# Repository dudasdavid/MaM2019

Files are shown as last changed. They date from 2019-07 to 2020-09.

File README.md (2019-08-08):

# MaM2019

Drivetrain:
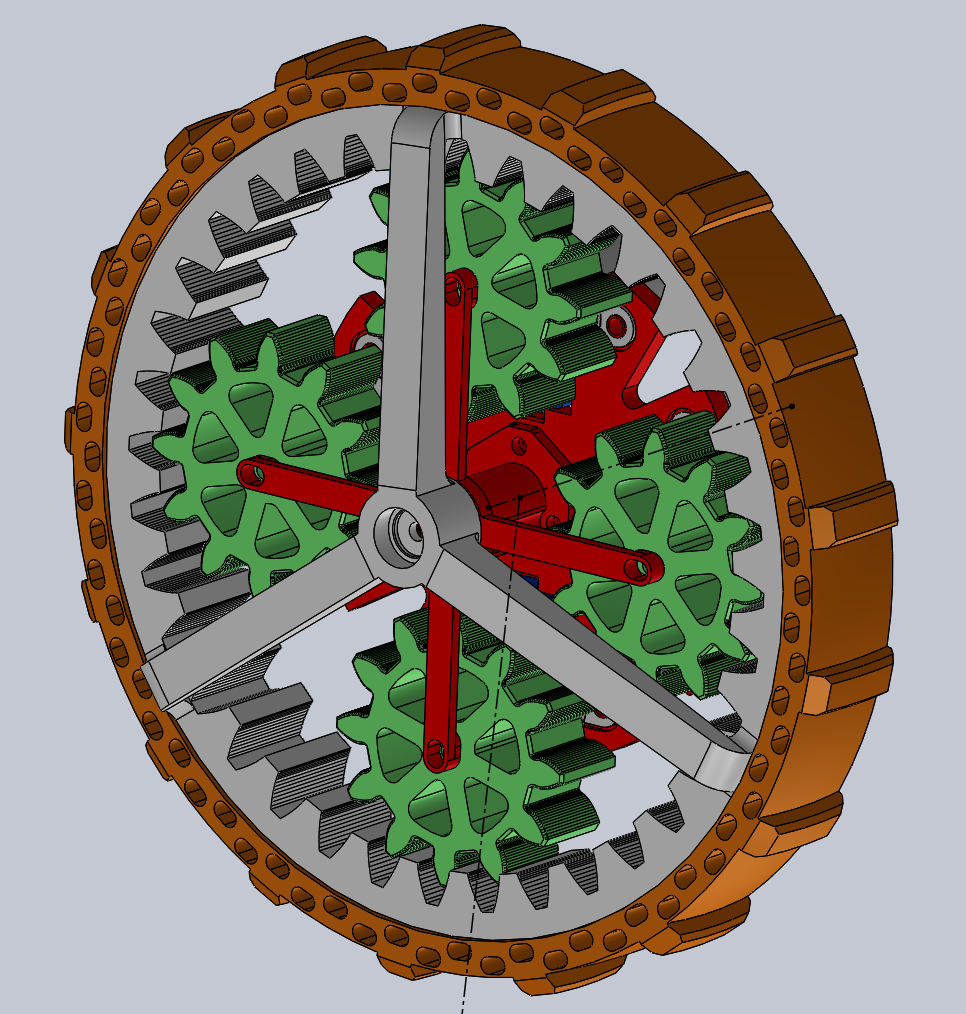
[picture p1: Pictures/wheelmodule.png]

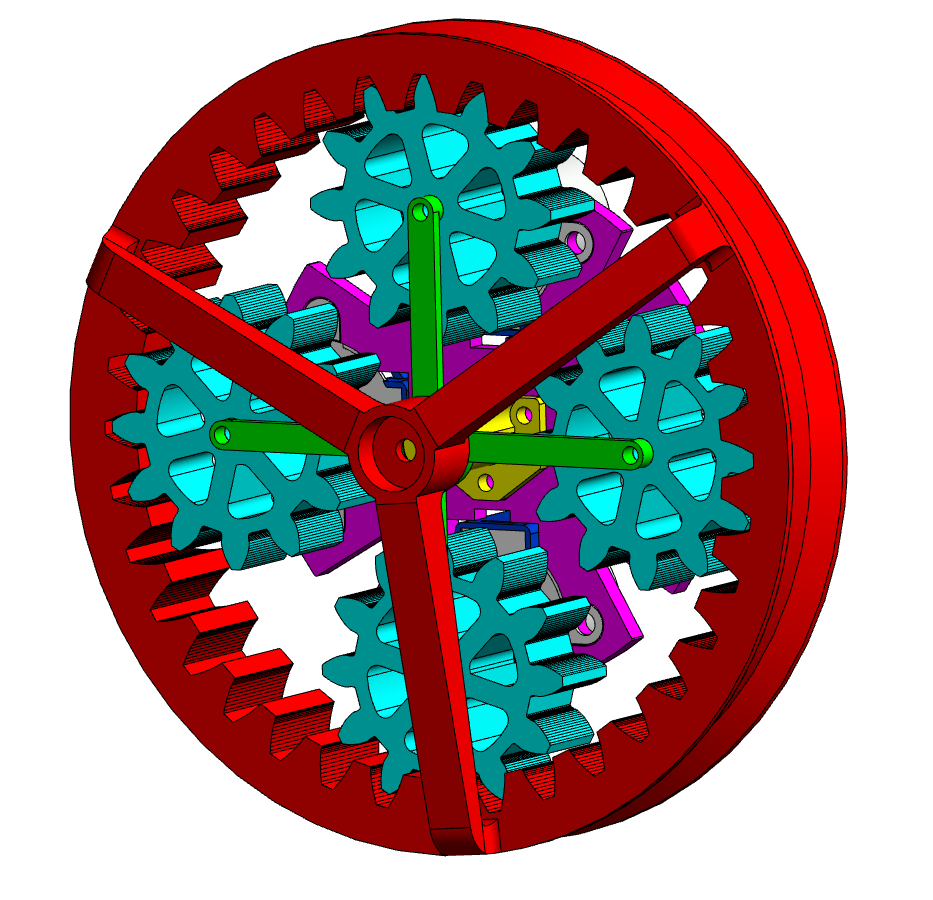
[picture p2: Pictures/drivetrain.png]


Mechanical parts:
- 4x M3x10: Spur gears --> Spur ribs
- 1x M3x25: Ring gear --> main axis
- 8x M3x8: Motors --> baseplate
- 3x M3x???: Main axis --> baseplate --> L bracket
- 4x M3x???: L bracket --> Chassis
- 2x 623 2Z Bearing (3X10X4): Ring gear

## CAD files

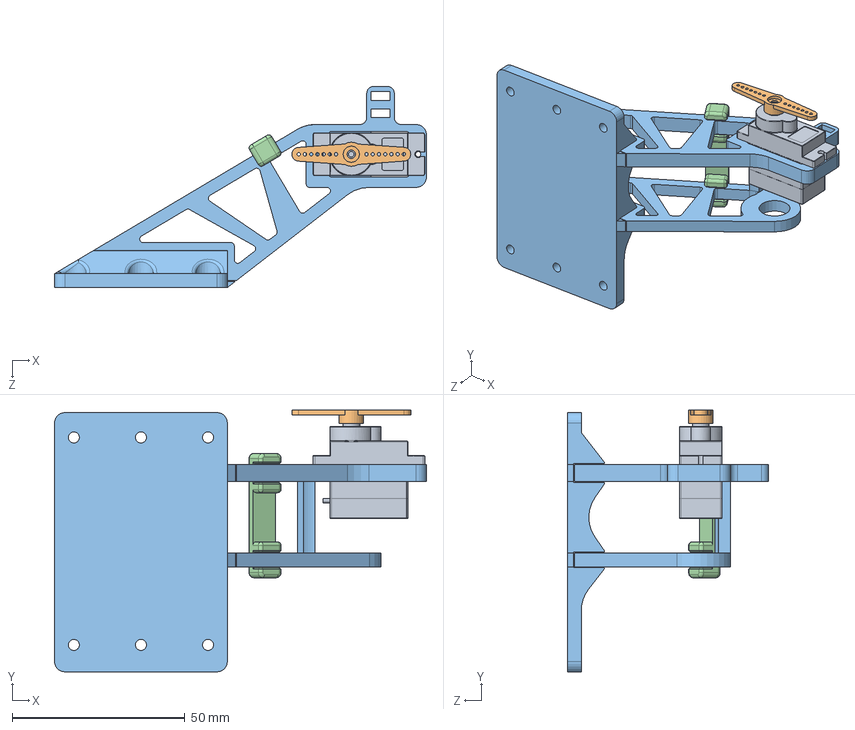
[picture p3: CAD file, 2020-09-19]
Mechanics/Solidworks/_LIFT.SLDASM
107.6 x 75.7 x 58.1 mm
microservoSG90
Part9^_LIFT
rib^_LIFT

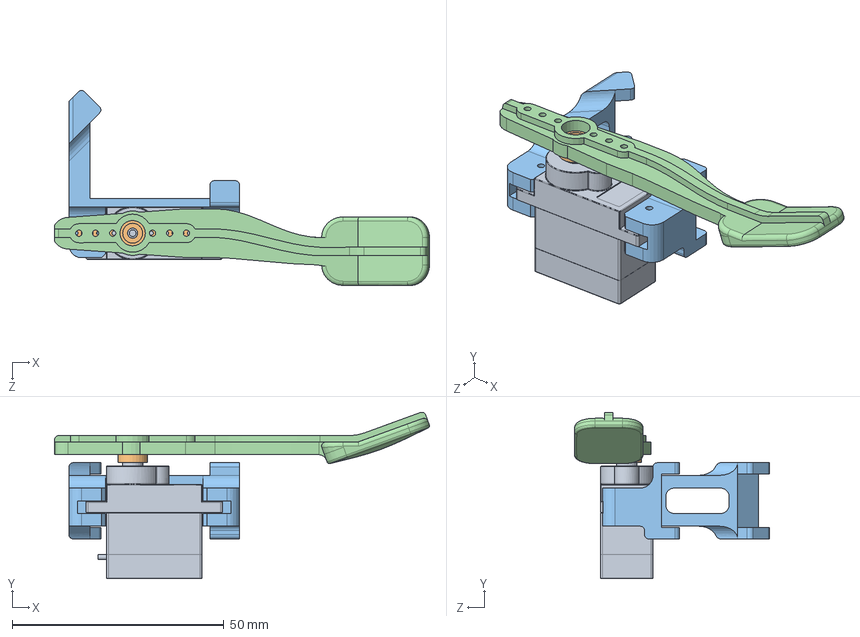
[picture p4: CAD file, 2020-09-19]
Mechanics/Solidworks/opener.SLDASM
88.6 x 39.3 x 46.1 mm
microservoSG90
microservoArm
Part5^opener
Part6^opener

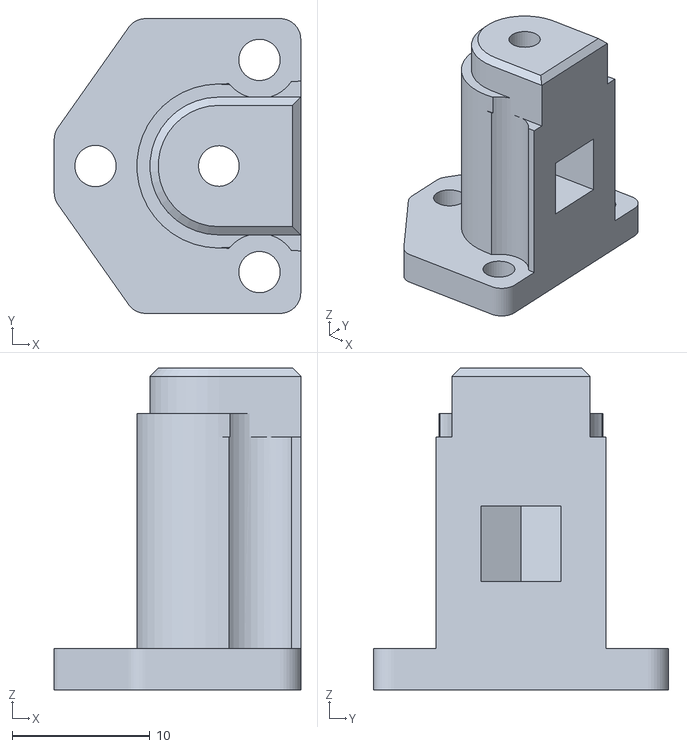
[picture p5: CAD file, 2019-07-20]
Mechanics/STL/MainAxis.STL
17.9 x 21.4 x 23.4

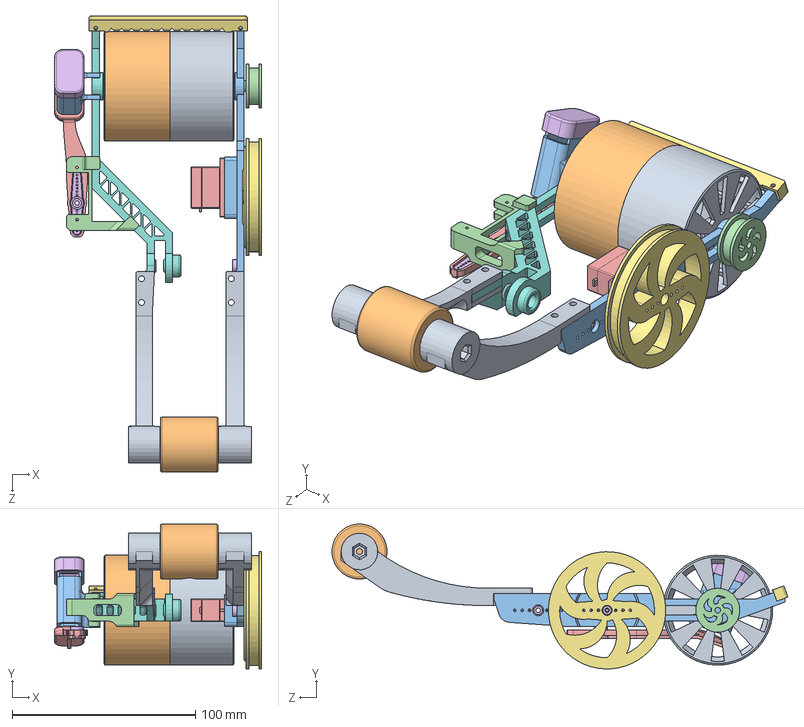
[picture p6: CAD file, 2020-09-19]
Mechanics/Solidworks/_COLLECTOR.SLDASM
113.1 x 79.1 x 248.8 mm
Copy of cylinder_1^_COLLECTOR
cylinder_2^_COLLECTOR
Part6^_COLLECTOR
Part7^_COLLECTOR
microservoArm x 3
Part8^_COLLECTOR
Part11^_COLLECTOR
bag
Part5^opener
Part6^opener
Part3^_COLLECTOR
Part9^_COLLECTOR

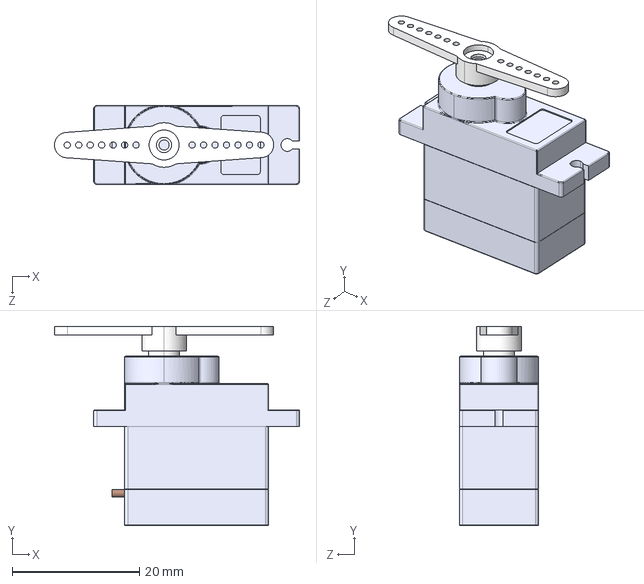
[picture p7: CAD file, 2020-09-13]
Mechanics/Solidworks/SG90/microservoAssembly.STEP
38.4 x 31.3 x 12.4 mm
microservoSG90
microservoArm_A2

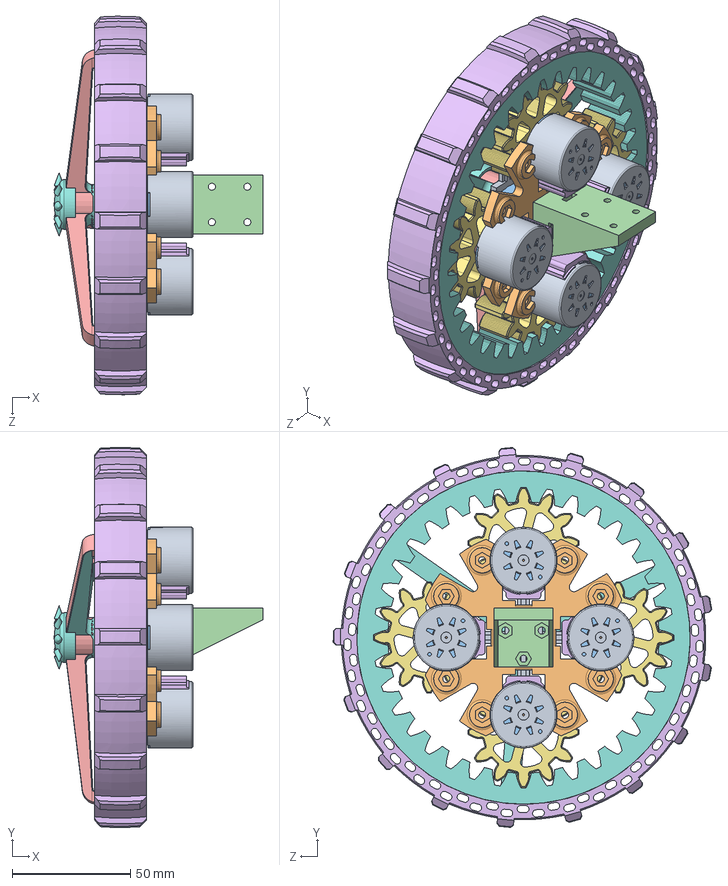
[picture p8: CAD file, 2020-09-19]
Mechanics/Solidworks/_DRIVE_v1.SLDASM
88.2 x 160.7 x 160.1 mm
El1 - 28BYJ-48 - 5 VDC x 4
El2 - 28BYJ-48 - 5 VDC x 4
El6 - 28BYJ-48 - 5 VDC x 4
El4 - 28BYJ-48 - 5 VDC x 4
El5 - 28BYJ-48 - 5 VDC x 4
El7 - 28BYJ-48 - 5 VDC x 4
El3 - 28BYJ-48 - 5 VDC x 4
El8 - 28BYJ-48 - 5 VDC x 4
El9 - 28BYJ-48 - 5 VDC x 4
El10 - 28BYJ-48 - 5 VDC x 4
El11 - 28BYJ-48 - 5 VDC x 4
El12 - 28BYJ-48 - 5 VDC x 4
El13 - 28BYJ-48 - 5 VDC x 4
El14 - 28BYJ-48 - 5 VDC x 4
SpurGear x 4
BasePlate
MainAxis^_DRIVE_v1
Lbracket
RingGear_corrected_diameter
RubberTire
SpurRibs_corrected
Cap^_DRIVE_v1

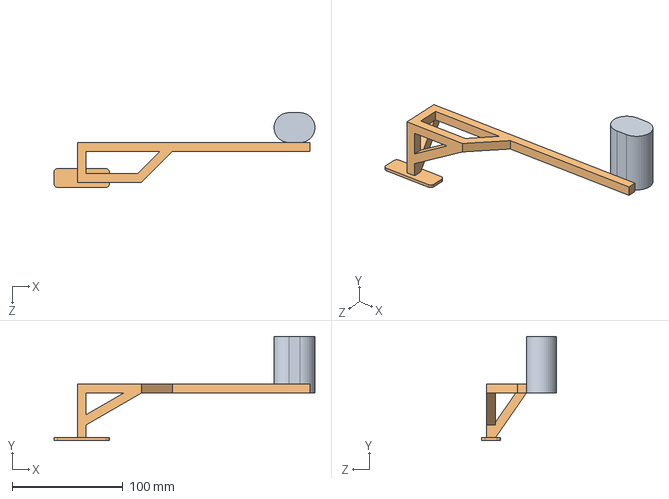
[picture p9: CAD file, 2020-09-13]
Mechanics/Solidworks/_EJECTOR.SLDASM
235.7 x 93.9 x 67.5 mm
Part2^_EJECTOR
Part7^_EJECTOR

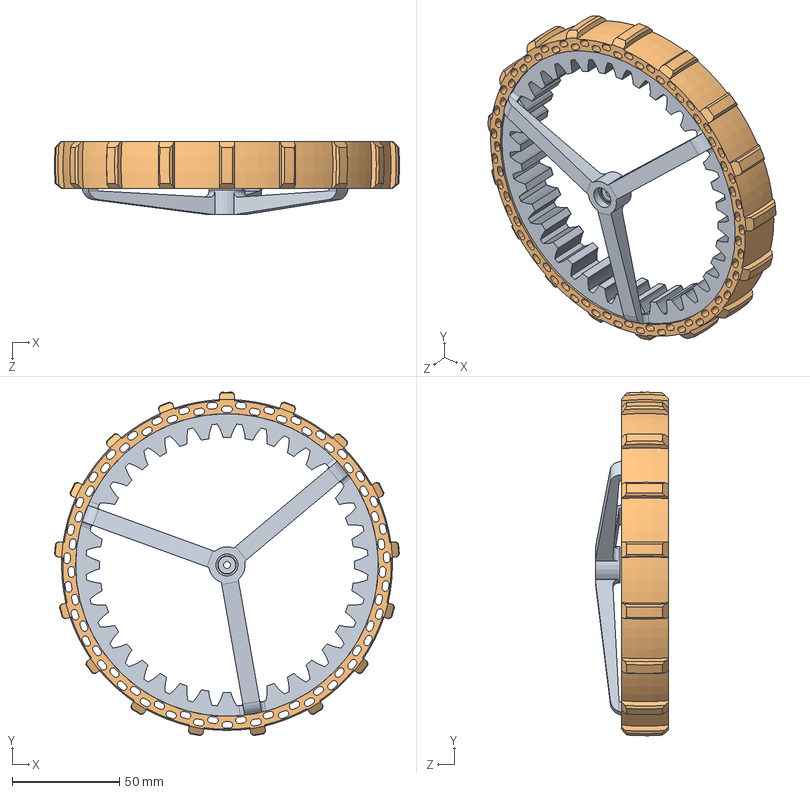
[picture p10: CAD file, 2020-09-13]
Mechanics/Solidworks/_TIRE.SLDASM
160.7 x 160.1 x 34.0 mm
RingGear_corrected_diameter
RubberTire

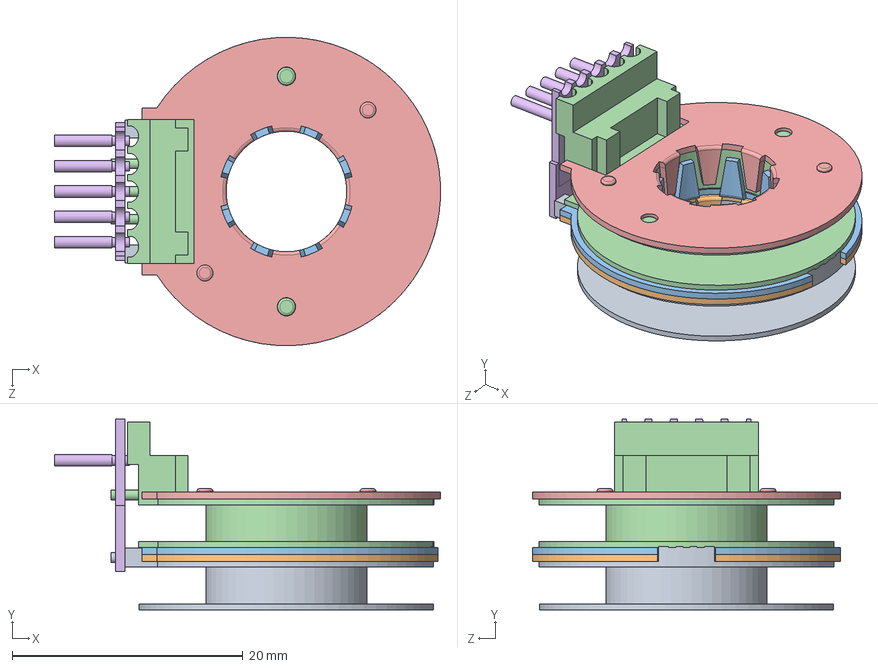
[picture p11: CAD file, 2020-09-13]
Mechanics/Solidworks/Inside 28BYJ-48 - 5 VDC SB.SLDPRT.SLDASM
33.5 x 16.5 x 26.7 mm
El6 - 28BYJ-48 - 5 VDC
El4 - 28BYJ-48 - 5 VDC
El5 - 28BYJ-48 - 5 VDC
El7 - 28BYJ-48 - 5 VDC
El3 - 28BYJ-48 - 5 VDC
El8 - 28BYJ-48 - 5 VDC

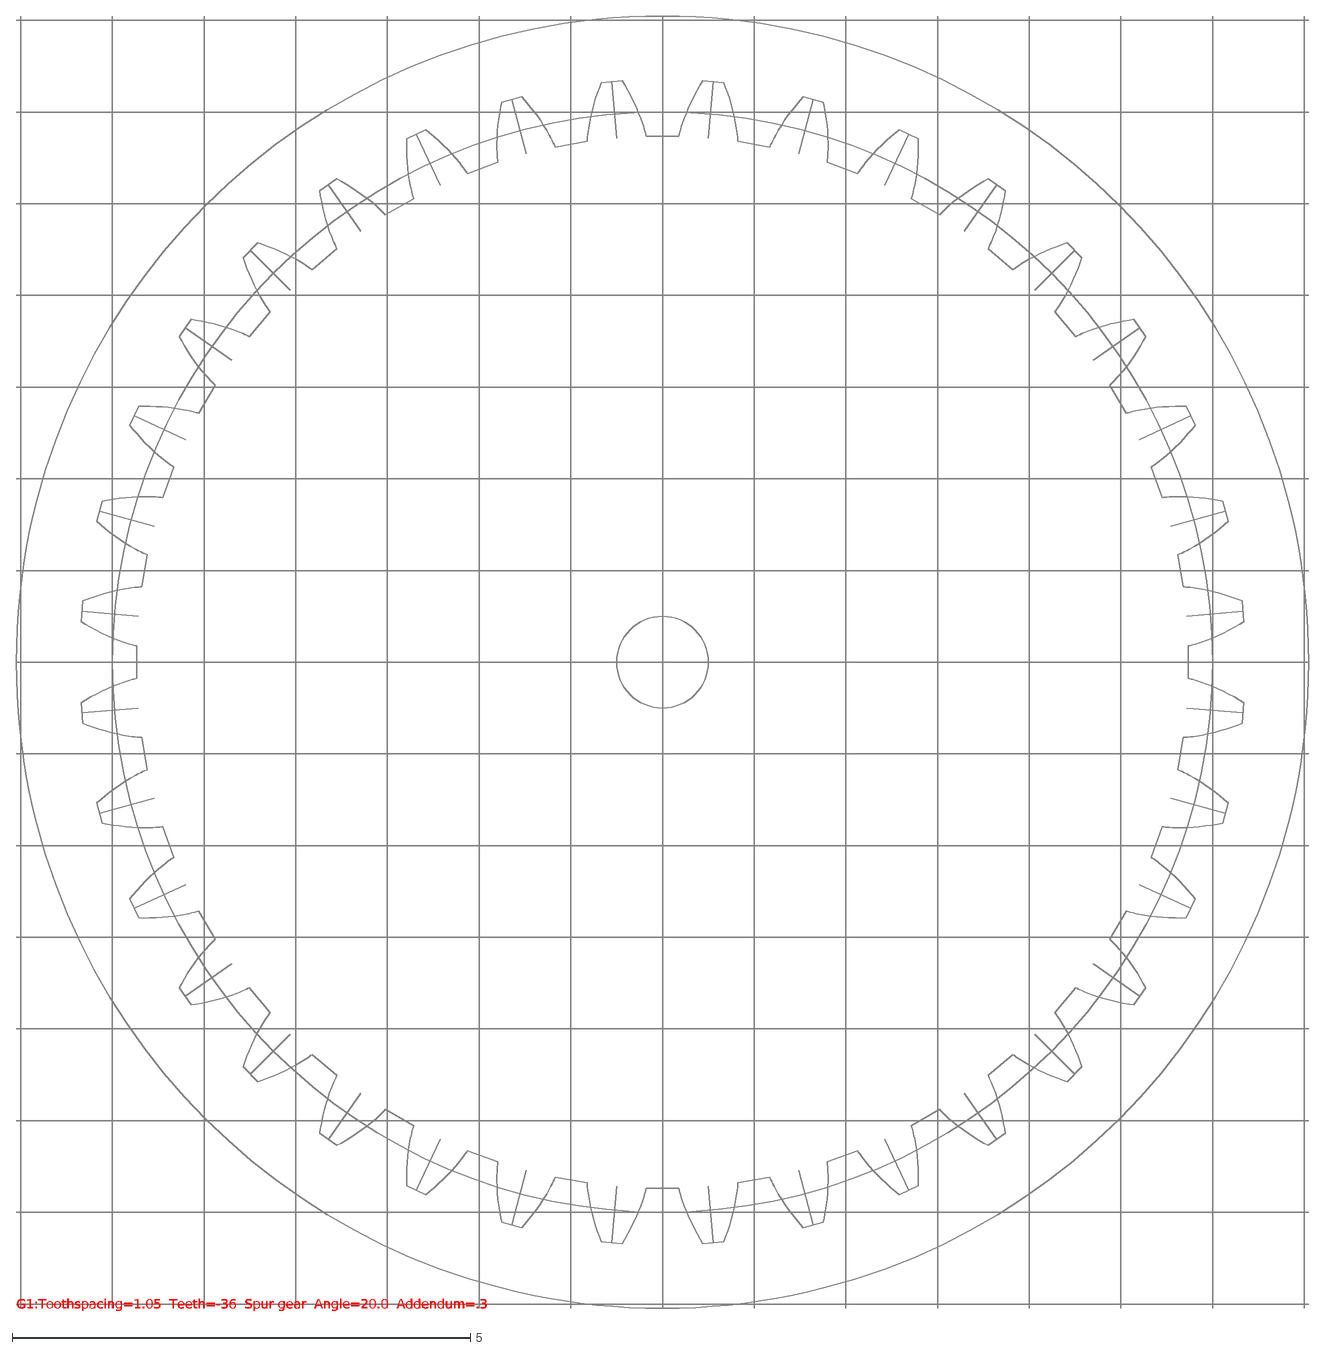
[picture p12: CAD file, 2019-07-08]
Mechanics/Gear design/ring_gear.dxf
G1:Toothspacing=1.05 Teeth=-36 Spur gear Angle=20.0 Addendum=.3

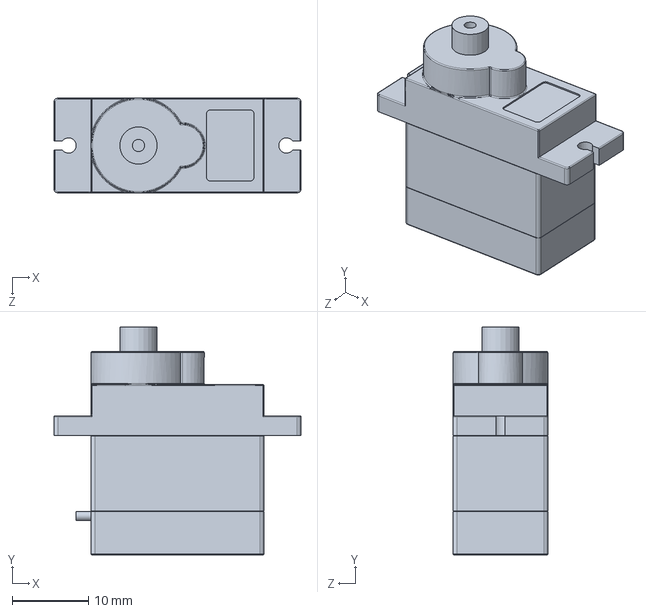
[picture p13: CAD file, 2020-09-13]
Mechanics/Solidworks/SG90/microservoSG90.SLDPRT
32.3 x 29.8 x 12.4 mm

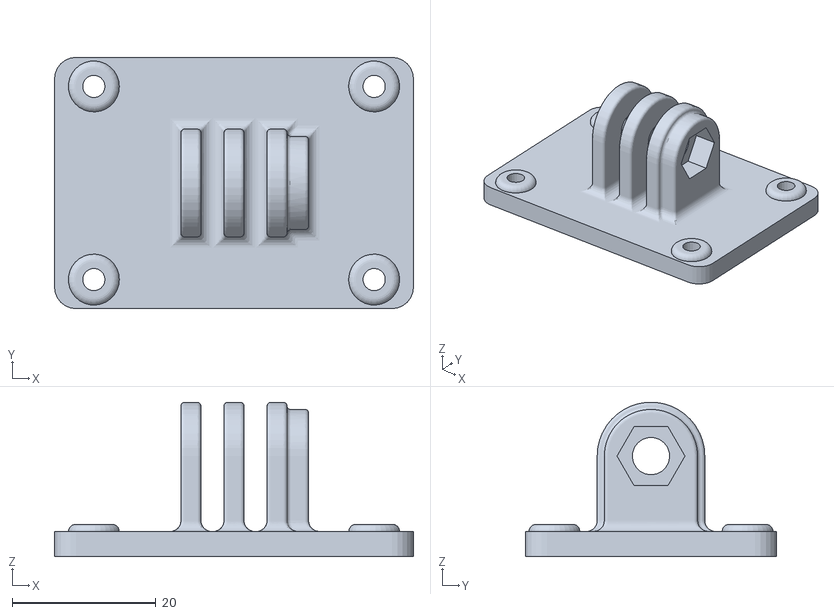
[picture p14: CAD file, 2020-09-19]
Mechanics/STL/camera/base.STL
50.0 x 35.0 x 21.5

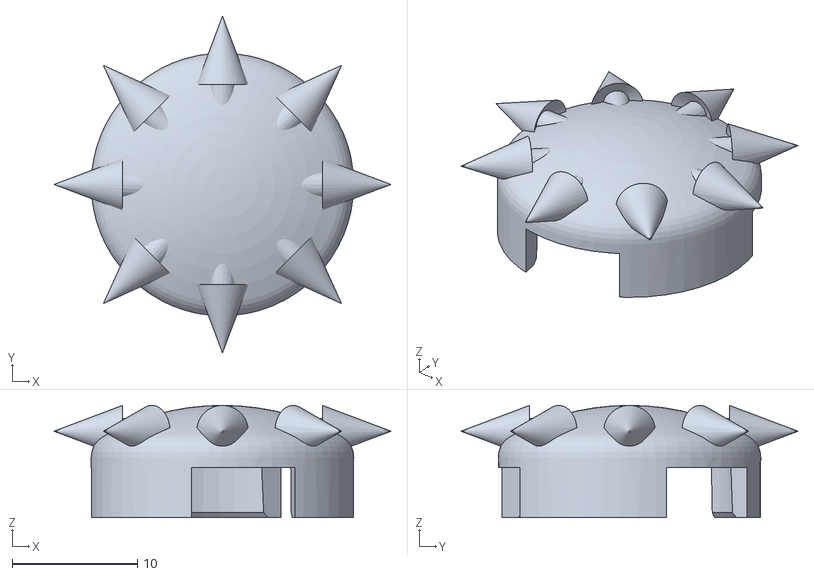
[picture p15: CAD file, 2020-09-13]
Mechanics/STL/cap.STL
27.0 x 27.0 x 8.98

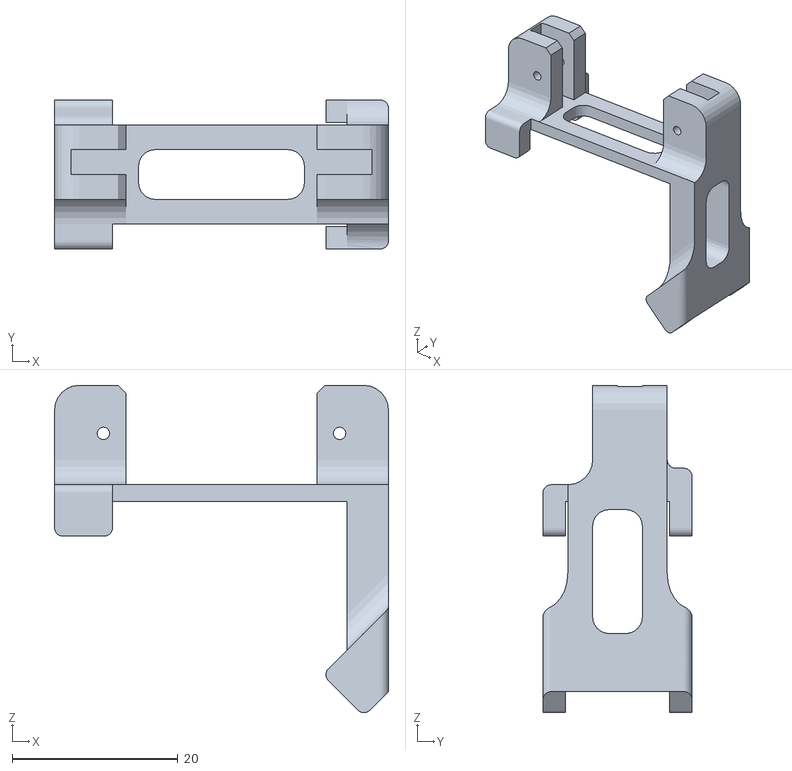
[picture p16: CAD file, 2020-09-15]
Mechanics/STL/ejector/servo.STL
40.3 x 18.0 x 39.5

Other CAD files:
Mechanics/STL/mainframe/pcb_holder.STL
Mechanics/STL/tower/rib.STL
Mechanics/Gear design/spur_gear.dxf
Mechanics/Gear design/gears_v1.dxf
Mechanics/STL/BasePlate.STL
Mechanics/STL/Lbracket.STL
Mechanics/STL/RingGear_corrected_diameter.STL
Mechanics/STL/RubberTire shrinked.STL
Mechanics/STL/RubberTire.STL
Mechanics/STL/SpurGear.STL
Mechanics/STL/SpurRibs_corrected.STL
Mechanics/STL/camera/camera_frame.STL
Mechanics/STL/camera/part1.STL
Mechanics/STL/camera/part2.STL
Mechanics/STL/ejector/arm.STL
Mechanics/STL/ejector/bag.STL
Mechanics/STL/ejector/ball_remover.STL
Mechanics/STL/ejector/cap.STL
Mechanics/STL/mainframe/base_1.STL
Mechanics/STL/mainframe/base_2.STL
Mechanics/STL/mainframe/side1_unmirrored.STL
Mechanics/STL/mainframe/side2_unmirrored.STL
Mechanics/STL/tower/COLLECTOR1.STL
Mechanics/STL/tower/COLLECTOR2.STL
Mechanics/STL/tower/COLLECTOR3.STL
Mechanics/STL/tower/COLLECTOR4.STL
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

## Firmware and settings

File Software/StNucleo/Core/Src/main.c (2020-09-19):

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
/* Includes ------------------------------------------------------------------*/
#include "main.h"
#include "cmsis_os.h"

/* USER CODE BEGIN Includes */
#include "motor.h"
#include "motors.h"
#include <math.h>
#include "x_nucleo_ihmxx.h"
#include "powerstep01.h"
/* USER CODE END Includes */

SPI_HandleTypeDef hspi1;

TIM_HandleTypeDef htim1;
TIM_HandleTypeDef htim3;
TIM_HandleTypeDef htim4;

UART_HandleTypeDef huart2;

/* Definitions for defaultTask */
osThreadId_t defaultTaskHandle;
const osThreadAttr_t defaultTask_attributes = {
  .name = "defaultTask",
  .priority = (osPriority_t) osPriorityNormal,
  .stack_size = 256 * 4
};
/* Definitions for servoTask */
osThreadId_t servoTaskHandle;
const osThreadAttr_t servoTask_attributes = {
  .name = "servoTask",
  .priority = (osPriority_t) osPriorityNormal,
  .stack_size = 256 * 4
};
/* Definitions for motorTask */
osThreadId_t motorTaskHandle;
const osThreadAttr_t motorTask_attributes = {
  .name = "motorTask",
  .priority = (osPriority_t) osPriorityNormal,
  .stack_size = 256 * 4
};
/* Definitions for commBuffer */
osMessageQueueId_t commBufferHandle;
const osMessageQueueAttr_t commBuffer_attributes = {
  .name = "commBuffer"
};
/* Definitions for paramUpdateMutex */
osMutexId_t paramUpdateMutexHandle;
const osMutexAttr_t paramUpdateMutex_attributes = {
  .name = "paramUpdateMutex"
};
/* USER CODE BEGIN PV */
static float drumAngle = 11.5f; //end
static float liftAngle = 12.f;   //full up position
static float ejector = 6.6f;    //closed
/* USER CODE END PV */

void SystemClock_Config(void);
static void MX_GPIO_Init(void);
static void MX_SPI1_Init(void);
static void MX_TIM3_Init(void);
static void MX_USART2_UART_Init(void);
static void MX_TIM4_Init(void);
static void MX_TIM1_Init(void);
void DefaultTask(void *argument);
void ServoTask(void *argument);
void MotorTask(void *argument);

/**
  * @brief  The application entry point.
  * @retval int
  */
int main(void)
{
  /* MCU Configuration--------------------------------------------------------*/

  /* Reset of all peripherals, Initializes the Flash interface and the Systick. */
  HAL_Init();

  /* USER CODE BEGIN Init */
  uwTickPrio = 15;
  /* USER CODE END Init */

  /* Configure the system clock */
  SystemClock_Config();

  /* Initialize all configured peripherals */
  MX_GPIO_Init();
  MX_SPI1_Init();
  MX_TIM3_Init();
  MX_USART2_UART_Init();
  MX_TIM4_Init();
  MX_TIM1_Init();
  /* USER CODE BEGIN 2 */

  HAL_TIM_PWM_Start(&htim1, TIM_CHANNEL_1);
  HAL_TIM_PWM_Start(&htim4, TIM_CHANNEL_3);
  HAL_TIM_PWM_Start(&htim4, TIM_CHANNEL_4);

  //TIM1->CCR1 = drumAngle*10000/100; // drum
  //TIM4->CCR3 = liftAngle*10000/100; // lift
  //TIM4->CCR4 = ejector*10000/100;   // ejector
  // 50Hz --> 20ms; 1ms ... 2ms --> 5% ... 10%

  /* USER CODE END 2 */

  /* Init scheduler */
  osKernelInitialize();
  /* Create the mutex(es) */
  /* creation of paramUpdateMutex */
  paramUpdateMutexHandle = osMutexNew(&paramUpdateMutex_attributes);

  /* USER CODE BEGIN RTOS_MUTEX */
	/* add mutexes, ... */
  /* USER CODE END RTOS_MUTEX */

  /* USER CODE BEGIN RTOS_SEMAPHORES */
	/* add semaphores, ... */
  /* USER CODE END RTOS_SEMAPHORES */

  /* USER CODE BEGIN RTOS_TIMERS */
	/* start timers, add new ones, ... */
  /* USER CODE END RTOS_TIMERS */

  /* Create the queue(s) */
  /* creation of commBuffer */
  commBufferHandle = osMessageQueueNew (32, sizeof(uint8_t), &commBuffer_attributes);

  /* USER CODE BEGIN RTOS_QUEUES */
	/* add queues, ... */
  /* USER CODE END RTOS_QUEUES */

  /* Create the thread(s) */
  /* creation of defaultTask */
  defaultTaskHandle = osThreadNew(DefaultTask, NULL, &defaultTask_attributes);

  /* creation of servoTask */
  servoTaskHandle = osThreadNew(ServoTask, NULL, &servoTask_attributes);

  /* creation of motorTask */
  motorTaskHandle = osThreadNew(MotorTask, NULL, &motorTask_attributes);

  /* USER CODE BEGIN RTOS_THREADS */
	/* add threads, ... */
  /* USER CODE END RTOS_THREADS */

  /* Start scheduler */
  osKernelStart();

  /* We should never get here as control is now taken by the scheduler */
  /* Infinite loop */
  /* USER CODE BEGIN WHILE */
	while (1) {
    /* USER CODE END WHILE */

    /* USER CODE BEGIN 3 */
	}
  /* USER CODE END 3 */
}

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
/* USER CODE BEGIN Header_DefaultTask */
static uint8_t receiveBuffer;

static volatile uint8_t referenceSpeed = 0;
static volatile uint8_t referenceAngle = 0;
static volatile uint8_t buttonState = 0;
static uint8_t messageCounter = 0xFF;

void HAL_UART_RxCpltCallback(UART_HandleTypeDef *huart) {
	osMessageQueuePut(commBufferHandle, &receiveBuffer, 0, 0);
	HAL_UART_Receive_IT(huart, &receiveBuffer, 1u);
}

void HAL_UART_ErrorCallback(UART_HandleTypeDef *huart) {
	HAL_UART_Receive_IT(huart, &receiveBuffer, 1u);
}

static bool process_message(const uint8_t message[4]) {
	if (messageCounter == message[3]) {
		// guard against repeated messages - a possible case of lost connection
		return false;
	}

	if ((message[0] <= 100) && (message[1] <= 180)) {
		//referenceSpeedOrig = receiveBuffer[1] / 10.0;
		//referenceSpeed = calcSpdRef_LUT(referenceSpeedOrig);
		if (osMutexAcquire(paramUpdateMutexHandle, 100) == osOK) {
			referenceSpeed = message[0];
			referenceAngle = message[1];
			buttonState = message[2];
			messageCounter = message[3];
			osMutexRelease(paramUpdateMutexHandle);
		}

		return true;
	} else {
		return false;
	}
}

/**
 * @brief  Function implementing the defaultTask thread.
 * @param  argument: Not used
 * @retval None
 */
/* USER CODE END Header_DefaultTask */
__weak void DefaultTask(void *argument)
{
  /* USER CODE BEGIN 5 */
	uint8_t message[5] = { 0 };
	uint32_t lastMessageReceived = HAL_GetTick();

	HAL_StatusTypeDef result = HAL_UART_Receive_IT(&huart2, &receiveBuffer, 1u);
	assert_param(result == HAL_OK);

	/* Infinite loop */
	for (;;) {
		if (osMessageQueueGetCount(commBufferHandle) >= 5) {
			osMessageQueueGet(commBufferHandle, &message[0], 0, 0);
			if (message[0] == 0xFF) {
				osMessageQueueGet(commBufferHandle, &message[1], 0, 0);
				osMessageQueueGet(commBufferHandle, &message[2], 0, 0);
				osMessageQueueGet(commBufferHandle, &message[3], 0, 0);
				osMessageQueueGet(commBufferHandle, &message[4], 0, 0);

				if (process_message(&message[1])) {
					lastMessageReceived = HAL_GetTick();

					for (int i = 0; i < MOTOR_COUNT; i++) {
						motors[i].state = ManualMode;
					}
				}
			}
		}

		if ((HAL_GetTick() - lastMessageReceived) > 1000) {
			// 1s timeout
			for (int i = 0; i < MOTOR_COUNT; i++) {
				motors[i].state = Idle;
			}
		}

		osDelay(2);
	}
  /* USER CODE END 5 */
}

/* USER CODE BEGIN Header_ServoTask */
/**
 * @brief Function implementing the servoTask thread.
 * @param argument: Not used
 * @retval None
 */
/* USER CODE END Header_ServoTask */
static float clip(float a, float min, float max) {
	if (a < min) {
		return min;
	}
	if (a > max) {
		return max;
	}

	return a;
}

static float normalize(uint8_t x) {
	return clip(x / 100.0, 0.0, 1.0);
}

__weak void ServoTask(void *argument)
{
  /* USER CODE BEGIN ServoTask */
	HAL_GPIO_WritePin(SERVO_EN_GPIO_Port, SERVO_EN_Pin, GPIO_PIN_SET);
	bool isStarted = false;
	bool rotateFlag = false;
	float timeStamp = 0.f;
	int phase = 0;

	/* Infinite loop */
	for (;;) {

		// Handle faszika ejector
		if (buttonState & 0x01){
			ejector = 5.f;
		}
		else {
			ejector = 6.6f;
		}

		// Handle sample collection
		if (buttonState & 0x02){
			liftAngle = 3.f;
			isStarted = true;
			rotateFlag = true;
		}
		else {
			if (isStarted){
				liftAngle = 8.f;
			}

			if (rotateFlag) {
				rotateFlag = false;
				drumAngle = drumAngle - 0.9f; // 0.9 is the angle increment!
				drumAngle = clip(drumAngle, 2.5f, 11.5f);
			}

		}

		// Handle sample eject
		if (buttonState & 0x04){
			liftAngle = 8.f;
			if (HAL_GetTick() - timeStamp > 500){
				timeStamp = HAL_GetTick();
				if (phase % 2 == 0){
					drumAngle = drumAngle + 1.5;
				}
				else {
					drumAngle = drumAngle - 0.8;
				}

				drumAngle = clip(drumAngle, 2.5f, 11.5f);

				phase++;
			}
		}

		// Set PWM duty cycles
		TIM1->CCR1 = drumAngle*10000/100; // drum 2.5...11.5
		TIM4->CCR3 = liftAngle*10000/100; // lift 3.0 down, 12 full top for start, 8 for eject
		TIM4->CCR4 = ejector*10000/100;   // ejector
		osDelay(20);
	}
  /* USER CODE END ServoTask */
}

/* USER CODE BEGIN Header_MotorTask */

static void rphi2lr(uint8_t r, uint8_t phi, float *left, float *right) {
#define SPEED_GAIN RPM_TO_STEP_P_S(400.0f)

	float rf = normalize(r);
	float phif = (2 * phi - 90.0f) * M_PI / 180.0f;

	float v = rf * cosf(phif) * 0.5f;
	float w = rf * sinf(phif) * 0.5f;

	*left = (v + w) * SPEED_GAIN;
	*right = (v - w) * SPEED_GAIN;
}

static void set_motor_speed(uint8_t id, float speed) {
	if (motors[id].state == ManualMode) {
		if (fabsf(speed) < RPM_TO_STEP_P_S(1.0f)) {
			BSP_MotorControl_CmdSoftHiZ(id);
		} else if (speed > 0) {
			BSP_MotorControl_CmdRun(id, FORWARD,
					Powerstep01_Speed_Steps_s_to_RegVal(speed));
		} else {
			BSP_MotorControl_CmdRun(id, BACKWARD,
					Powerstep01_Speed_Steps_s_to_RegVal(fabsf(speed)));
		}
	} else {
		BSP_MotorControl_CmdSoftHiZ(id);
	}
}

/**
 * @brief Function implementing the motorTask thread.
 * @param argument: Not used
 * @retval None
 */
/* USER CODE END Header_MotorTask */
__weak void MotorTask(void *argument)
{
  /* USER CODE BEGIN MotorTask */
	motors_Init();

	for (int i = 0; i < MOTOR_COUNT; i++) {
		motors[i].state = Idle;
	}

	/* Infinite loop */
	for (;;) {
		if (osMutexAcquire(paramUpdateMutexHandle, 10) == osOK) {
			float left;
			float right;
			rphi2lr(referenceSpeed, referenceAngle, &left, &right);
			osMutexRelease(paramUpdateMutexHandle);

			set_motor_speed(0, -1.0f * left);
			set_motor_speed(1, right);
		}
		osDelay(10);
	}
  /* USER CODE END MotorTask */
}

/**
  * @brief  Period elapsed callback in non blocking mode
  * @note   This function is called  when TIM2 interrupt took place, inside
  * HAL_TIM_IRQHandler(). It makes a direct call to HAL_IncTick() to increment
  * a global variable "uwTick" used as application time base.
  * @param  htim : TIM handle
  * @retval None
  */
void HAL_TIM_PeriodElapsedCallback(TIM_HandleTypeDef *htim)
{
  if (htim->Instance == TIM2) {
    HAL_IncTick();
  }
}

/**
  * @brief  This function is executed in case of error occurrence.
  * @retval None
  */
void Error_Handler(void)
{
  /* USER CODE BEGIN Error_Handler_Debug */
	/* User can add his own implementation to report the HAL error return state */
	while (1) {

	}
  /* USER CODE END Error_Handler_Debug */
}

#ifdef  USE_FULL_ASSERT
/**
  * @brief  Reports the name of the source file and the source line number
  *         where the assert_param error has occurred.
  * @param  file: pointer to the source file name
  * @param  line: assert_param error line source number
  * @retval None
  */
void assert_failed(uint8_t *file, uint32_t line)
{
  /* USER CODE BEGIN 6 */
	Error_Handler();
  /* User can add his own implementation to report the file name and line number,
     tex: printf("Wrong parameters value: file %s on line %d\r\n", file, line) */
  /* USER CODE END 6 */
}
#endif /* USE_FULL_ASSERT */

/************************ (C) COPYRIGHT STMicroelectronics *****END OF FILE****/

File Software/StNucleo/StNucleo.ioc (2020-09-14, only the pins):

Mcu.UserName=STM32F401RETx
PA10.GPIO_Label=BSP_MOTOR_CONTROL_BOARD_FLAG
PA10.Signal=GPXTI10
PA13.Signal=SYS_JTMS-SWDIO
PA14.Signal=SYS_JTCK-SWCLK
PA2.Signal=USART2_TX
PA3.Signal=USART2_RX
PA5.Signal=SPI1_SCK
PA6.Signal=SPI1_MISO
PA7.Signal=SPI1_MOSI
PA8.Signal=S_TIM1_CH1
PA9.GPIO_Label=BSP_MOTOR_CONTROL_BOARD_STBY_RESET
PA9.Signal=GPIO_Output
PB12.GPIO_Label=SERVO_EN
PB12.Signal=GPIO_Output
PB5.GPIO_Label=BSP_MOTOR_CONTROL_BOARD_BUSY
PB5.Signal=GPXTI5
PB6.GPIO_Label=BSP_MOTOR_CONTROL_BOARD_CS
PB6.Signal=GPIO_Output
PB8.Signal=S_TIM4_CH3
PB9.Signal=S_TIM4_CH4
PC14-OSC32_IN.Signal=RCC_OSC32_IN
PC15-OSC32_OUT.Signal=RCC_OSC32_OUT
PC7.GPIO_Label=BSP_MOTOR_CONTROL_BOARD_STEP_CLOCK
PC7.Signal=S_TIM3_CH2

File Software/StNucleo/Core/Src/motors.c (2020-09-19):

#include "main.h"
#include "motors.h"
#include "powerstep01.h"
#include "stm32f4xx_hal.h"
#include "x_nucleo_ihmxx.h"

#include <stddef.h>

Motor_t motors[MOTOR_COUNT];
static volatile uint16_t gLastError;

/* Initialization parameters for current mode */
union powerstep01_Init_u initDeviceParameters = {
/* common parameters */
.cm.cp.cmVmSelection = POWERSTEP01_CM_VM_CURRENT, // enum powerstep01_CmVm_t
		5959, // Acceleration rate in step/s2, range 14.55 to 59590 steps/s^2
		5959, // Deceleration rate in step/s2, range 14.55 to 59590 steps/s^2
		RPM_TO_STEP_P_S(MOTOR_MAX_SPEED_RPM), // Maximum speed in step/s, range 15.25 to 15610 steps/s
		0, // Minimum speed in step/s, range 0 to 976.3 steps/s
		POWERSTEP01_LSPD_OPT_OFF, // Low speed optimization bit, enum powerstep01_LspdOpt_t
		RPM_TO_STEP_P_S(FULL_STEP_SPEED_RPM), // Full step speed in step/s, range 7.63 to 15625 steps/s
		POWERSTEP01_BOOST_MODE_ON, // Boost of the amplitude square wave, enum powerstep01_BoostMode_t
		281.25, // Overcurrent threshold settings via enum powerstep01_OcdTh_t
		STEP_MODE_1_4, // Step mode settings via enum motorStepMode_t
		POWERSTEP01_SYNC_SEL_DISABLED, // Synch. Mode settings via enum powerstep01_SyncSel_t
		(POWERSTEP01_ALARM_EN_OVERCURRENT
				| POWERSTEP01_ALARM_EN_THERMAL_SHUTDOWN
				| POWERSTEP01_ALARM_EN_THERMAL_WARNING
				| POWERSTEP01_ALARM_EN_UVLO
				| POWERSTEP01_ALARM_EN_STALL_DETECTION
				| POWERSTEP01_ALARM_EN_WRONG_NPERF_CMD), // Alarm settings via bitmap enum powerstep01_AlarmEn_t
		POWERSTEP01_IGATE_64mA, // Gate sink/source current via enum powerstep01_Igate_t
		POWERSTEP01_TBOOST_0ns, // Duration of the overboost phase during gate turn-off via enum powerstep01_Tboost_t
		POWERSTEP01_TCC_500ns, // Controlled current time via enum powerstep01_Tcc_t
		POWERSTEP01_WD_EN_DISABLE, // External clock watchdog, enum powerstep01_WdEn_t
		POWERSTEP01_TBLANK_375ns, // Duration of the blanking time via enum powerstep01_TBlank_t
		POWERSTEP01_TDT_125ns, // Duration of the dead time via enum powerstep01_Tdt_t
		/* current mode parameters */
		100, // Hold torque in mV, range from 7.8mV to 1000 mV
		200, // Running torque in mV, range from 7.8mV to 1000 mV
		100, // Acceleration torque in mV, range from 7.8mV to 1000 mV
		100, // Deceleration torque in mV, range from 7.8mV to 1000 mV
		POWERSTEP01_TOFF_FAST_8us, //Maximum fast decay time , enum powerstep01_ToffFast_t
		POWERSTEP01_FAST_STEP_12us, //Maximum fall step time , enum powerstep01_FastStep_t
		3.0, // Minimum on-time in us, range 0.5us to 64us
		21.0, // Minimum off-time in us, range 0.5us to 64us
		POWERSTEP01_CONFIG_INT_16MHZ_OSCOUT_2MHZ, // Clock setting , enum powerstep01_ConfigOscMgmt_t
		POWERSTEP01_CONFIG_SW_HARD_STOP, // External switch hard stop interrupt mode, enum powerstep01_ConfigSwMode_t
		POWERSTEP01_CONFIG_TQ_REG_TVAL_USED, // External torque regulation enabling , enum powerstep01_ConfigEnTqReg_t
		POWERSTEP01_CONFIG_VS_COMP_DISABLE, // Motor Supply Voltage Compensation enabling , enum powerstep01_ConfigEnVscomp_t
		POWERSTEP01_CONFIG_OC_SD_DISABLE, // Over current shutwdown enabling, enum powerstep01_ConfigOcSd_t
		POWERSTEP01_CONFIG_UVLOVAL_LOW, // UVLO Threshold via powerstep01_ConfigUvLoVal_t
		POWERSTEP01_CONFIG_VCCVAL_15V, // VCC Val, enum powerstep01_ConfigVccVal_t
		POWERSTEP01_CONFIG_TSW_048us, // Switching period, enum powerstep01_ConfigTsw_t
		POWERSTEP01_CONFIG_PRED_DISABLE, // Predictive current enabling , enum powerstep01_ConfigPredEn_t
		};

static void MyBusyInterruptHandler(void);
static void MyFlagInterruptHandler(void);
static void MyErrorHandler(uint16_t error);

void motors_Init() {
	//----- Init of the Powerstep01 library
	/* Set the Powerstep01 library to use 1 device */
	BSP_MotorControl_SetNbDevices(BSP_MOTOR_CONTROL_BOARD_ID_POWERSTEP01,
	MOTOR_COUNT);
	/* When BSP_MotorControl_Init is called with NULL pointer,                  */
	/* the Powerstep01 registers are set with the predefined values from file   */
	/* powerstep01_target_config.h, otherwise the registers are set using the   */
	/* powerstep01_Init_u relevant union of structure values.                   */
	/* The first call to BSP_MotorControl_Init initializes the first device     */
	/* whose Id is 0.                                                           */
	/* The nth call to BSP_MotorControl_Init initializes the nth device         */
	/* whose Id is n-1.                                                         */
	/* Uncomment the call to BSP_MotorControl_Init below to initialize the      */
	/* device with the union declared in the the main.c file and comment the    */
	/* subsequent call having the NULL pointer                                  */
	for (int i = 0; i < MOTOR_COUNT; i++) {
		BSP_MotorControl_Init(BSP_MOTOR_CONTROL_BOARD_ID_POWERSTEP01,
				&initDeviceParameters);
		motors[i].state = Idle;
	}

	/* Attach the function MyFlagInterruptHandler (defined below) to the flag interrupt */
	BSP_MotorControl_AttachFlagInterrupt(MyFlagInterruptHandler);

	/* Attach the function MyBusyInterruptHandler (defined below) to the busy interrupt */
	BSP_MotorControl_AttachBusyInterrupt(MyBusyInterruptHandler);

	/* Attach the function Error_Handler (defined below) to the error Handler*/
	BSP_MotorControl_AttachErrorHandler(MyErrorHandler);

	for (int i = 0; i < MOTOR_COUNT; i++) {
		BSP_MotorControl_CmdSoftHiZ(i);
	}
}

/**
 * @brief  This function is the User handler for the flag interrupt
 * @param  None
 * @retval None
 */
void MyFlagInterruptHandler(void) {
	/* Get the value of the status register via the command GET_STATUS */
	for (int i = 0; i < MOTOR_COUNT; i++) {
		uint16_t statusRegister = BSP_MotorControl_CmdGetStatus(i);
		/* Check STALL_A flag: if not set, there is a Stall condition on bridge A */
		if ((statusRegister & POWERSTEP01_STATUS_STALL_A) == 0
				|| (statusRegister & POWERSTEP01_STATUS_STALL_B) == 0) {
			//overcurrent detection

		}
	}

}

/**
 * @brief  This function is the User handler for the busy interrupt
 * @param  None
 * @retval None
 */
void MyBusyInterruptHandler(void) {

	if (BSP_MotorControl_CheckBusyHw()) {
		/* Busy pin is low, so at list one Powerstep01 chip is busy */
		/* To be customized (for example Switch on a LED) */
	} else {
		/* To be customized (for example Switch off a LED) */
	}
}

/**
 * @brief  This function is executed in case of error occurrence.
 * @param[in] error Number of the error
 * @retval None
 */
void MyErrorHandler(uint16_t error) {
	/* Backup error number */
	gLastError = error;

	/* Infinite loop */
	while (1) {
	}
}

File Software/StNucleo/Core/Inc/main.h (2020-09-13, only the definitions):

#define SERVO_EN_Pin GPIO_PIN_12
#define SERVO_EN_GPIO_Port GPIOB
#define BSP_MOTOR_CONTROL_BOARD_STEP_CLOCK_Pin GPIO_PIN_7
#define BSP_MOTOR_CONTROL_BOARD_STEP_CLOCK_GPIO_Port GPIOC
#define BSP_MOTOR_CONTROL_BOARD_STBY_RESET_Pin GPIO_PIN_9
#define BSP_MOTOR_CONTROL_BOARD_STBY_RESET_GPIO_Port GPIOA
#define BSP_MOTOR_CONTROL_BOARD_FLAG_Pin GPIO_PIN_10
#define BSP_MOTOR_CONTROL_BOARD_FLAG_GPIO_Port GPIOA
#define BSP_MOTOR_CONTROL_BOARD_FLAG_EXTI_IRQn EXTI15_10_IRQn
#define BSP_MOTOR_CONTROL_BOARD_BUSY_Pin GPIO_PIN_5
#define BSP_MOTOR_CONTROL_BOARD_BUSY_GPIO_Port GPIOB
#define BSP_MOTOR_CONTROL_BOARD_BUSY_EXTI_IRQn EXTI9_5_IRQn
#define BSP_MOTOR_CONTROL_BOARD_CS_Pin GPIO_PIN_6
#define BSP_MOTOR_CONTROL_BOARD_CS_GPIO_Port GPIOB

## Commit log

2019-07-08 3D model of robot drivetrain
    [28BYJ-48 - 5 VDC SB.SLDPRT.SLDASM, BasePlate.STL, BasePlate.sldprt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]
2019-07-08 Folder restructuring
    [28BYJ-48 - 5 VDC SB.SLDPRT.SLDASM, BasePlate.STL, BasePlate.sldprt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]
2019-07-20 fine tune of some parts
    [BasePlate.STL, BasePlate.sldprt, MainAxis.STL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]
2019-08-08 New mechanical parts, tire and L bracket
    [Lbracket.STL, Lbracket.sldprt, RingGear.STL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]
2019-08-08 Wheel module update
    [BasePlate.sldprt, RingGear_corrected_diameter.SLDPRT, RubberTire.sldprt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]
2019-08-21 Rubber tire and fixed ring gear STLs
    [RubberTire.STL]
2020-09-12 Drive motors
2020-09-12 Use timer1 for 50Hz pwm
2020-09-12 Stop on assert fail
    [main.c]
2020-09-12 Set up interrupt priorities for RTOS, fix system timer prio
    [StNucleo.ioc, main.c]
2020-09-12 Make sure motors can spin backwards, sides spin in opposite dir
2020-09-12 Fix types, spin motors on power up
    [main.c]
2020-09-13 CAD: Stepper and servo updates
    [28BYJ-48 - 5 VDC SB.SLDPRT.SLDASM, El1 - 28BYJ-48 - 5 VDC.SLDPRT, El10 - 28BYJ-48 - 5 VDC.SLDPRT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]
2020-09-13 CAD: update of main parts
    [BasePlate.sldprt, Lbracket.sldprt, RingGear.SLDPRT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]
2020-09-13 CAD: update of main assemblies
    [_COLLECTOR.SLDASM, _DRIVE_v1.SLDASM, _EJECTOR.SLDASM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]
2020-09-13 STL files for 3D printing
    [COLLECTOR1.STL, COLLECTOR2.STL, COLLECTOR3.STL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]
2020-09-13 arduino test code update
2020-09-13 changes in SPI CS, UART2 and TIM3
2020-09-13 change SPI prescaler from 4 to 32
2020-09-13 changes in UART1->2 and TIM3
2020-09-14 change servo PWMs to TIM1 and TIM4
2020-09-14 UART tweaks (change IT prio), check for error
    [StNucleo.ioc, main.c]
2020-09-14 Fix joystick conversion, decrease allowed acceleration
    [main.c, motors.c]
2020-09-15 servo ejector for faszika
    [_COLLECTOR.SLDASM, _DRIVE_v1.SLDASM, _LIFT.SLDASM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]
2020-09-15 STL files for 3D printing the ejector
    [arm.STL, bag.STL, ball_remover.STL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]
2020-09-15 servo angle tuning with STM studio
2020-09-15 servo handling
2020-09-19 camera holder 3D models
    [_COLLECTOR.SLDASM, _DRIVE_v1.SLDASM, _LIFT.SLDASM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]
2020-09-19 camera holder STL files for 3D printing
    [base.STL, camera_frame.STL, part1.STL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]
2020-09-19 set default servo angles
2020-09-19 handle sample collection, ejecting, etc
2020-09-19 remove unnecessary servo initialization

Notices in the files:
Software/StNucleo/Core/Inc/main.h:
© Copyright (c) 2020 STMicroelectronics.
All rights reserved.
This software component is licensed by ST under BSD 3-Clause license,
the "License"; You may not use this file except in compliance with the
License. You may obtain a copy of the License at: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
